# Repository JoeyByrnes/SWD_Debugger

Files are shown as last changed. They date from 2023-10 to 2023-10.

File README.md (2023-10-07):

# SWD_Debugger
Design files for an SWD debugger based on the <a href="https://github.com/electronut/ElectronutLabs-Bumpy">bumpy probe</a>. Compatible with Black Magic Probe and ST-Link V2 firmware. 

Hardware Changes from Bumpy 2.0 Project:
- Changed male USB-A plug to a female USB-C receptacle
- Changed pinout of the SWD/UART pins so that all SWD related pins are on top and all UART & power pins are on bottom
- Changed form factor and created an enclosure out of a cover PCB and 3d printed spacers.
- Changed resonator to an equivalent option in a different package
- Changed STM32 to a different package of the same product (for sourcing purposes at the time of designing)
<br>
<br>
<p align="center">
  
</p>

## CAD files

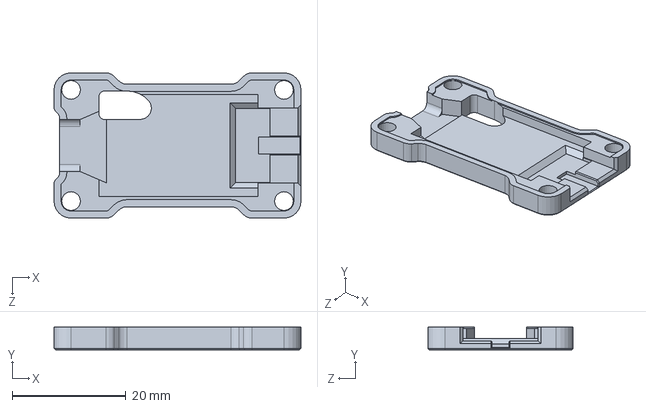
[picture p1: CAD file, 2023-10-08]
3D_Prints/Debugger_Print_Top.SLDPRT
43.5 x 4.00 x 25.6 mm

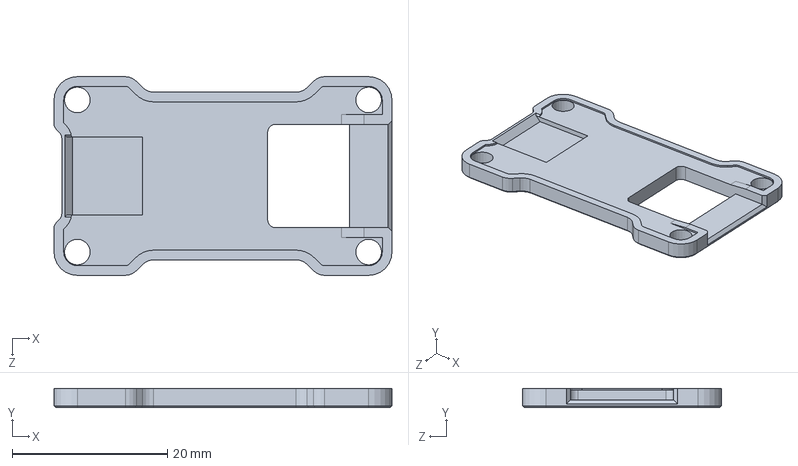
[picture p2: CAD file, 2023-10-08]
3D_Prints/Debugger_Print_Bottom.SLDPRT
43.5 x 2.50 x 25.6 mm

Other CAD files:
3D_Prints/Debugger_Print_Bottom.STL
3D_Prints/Debugger_Print_Top.STL

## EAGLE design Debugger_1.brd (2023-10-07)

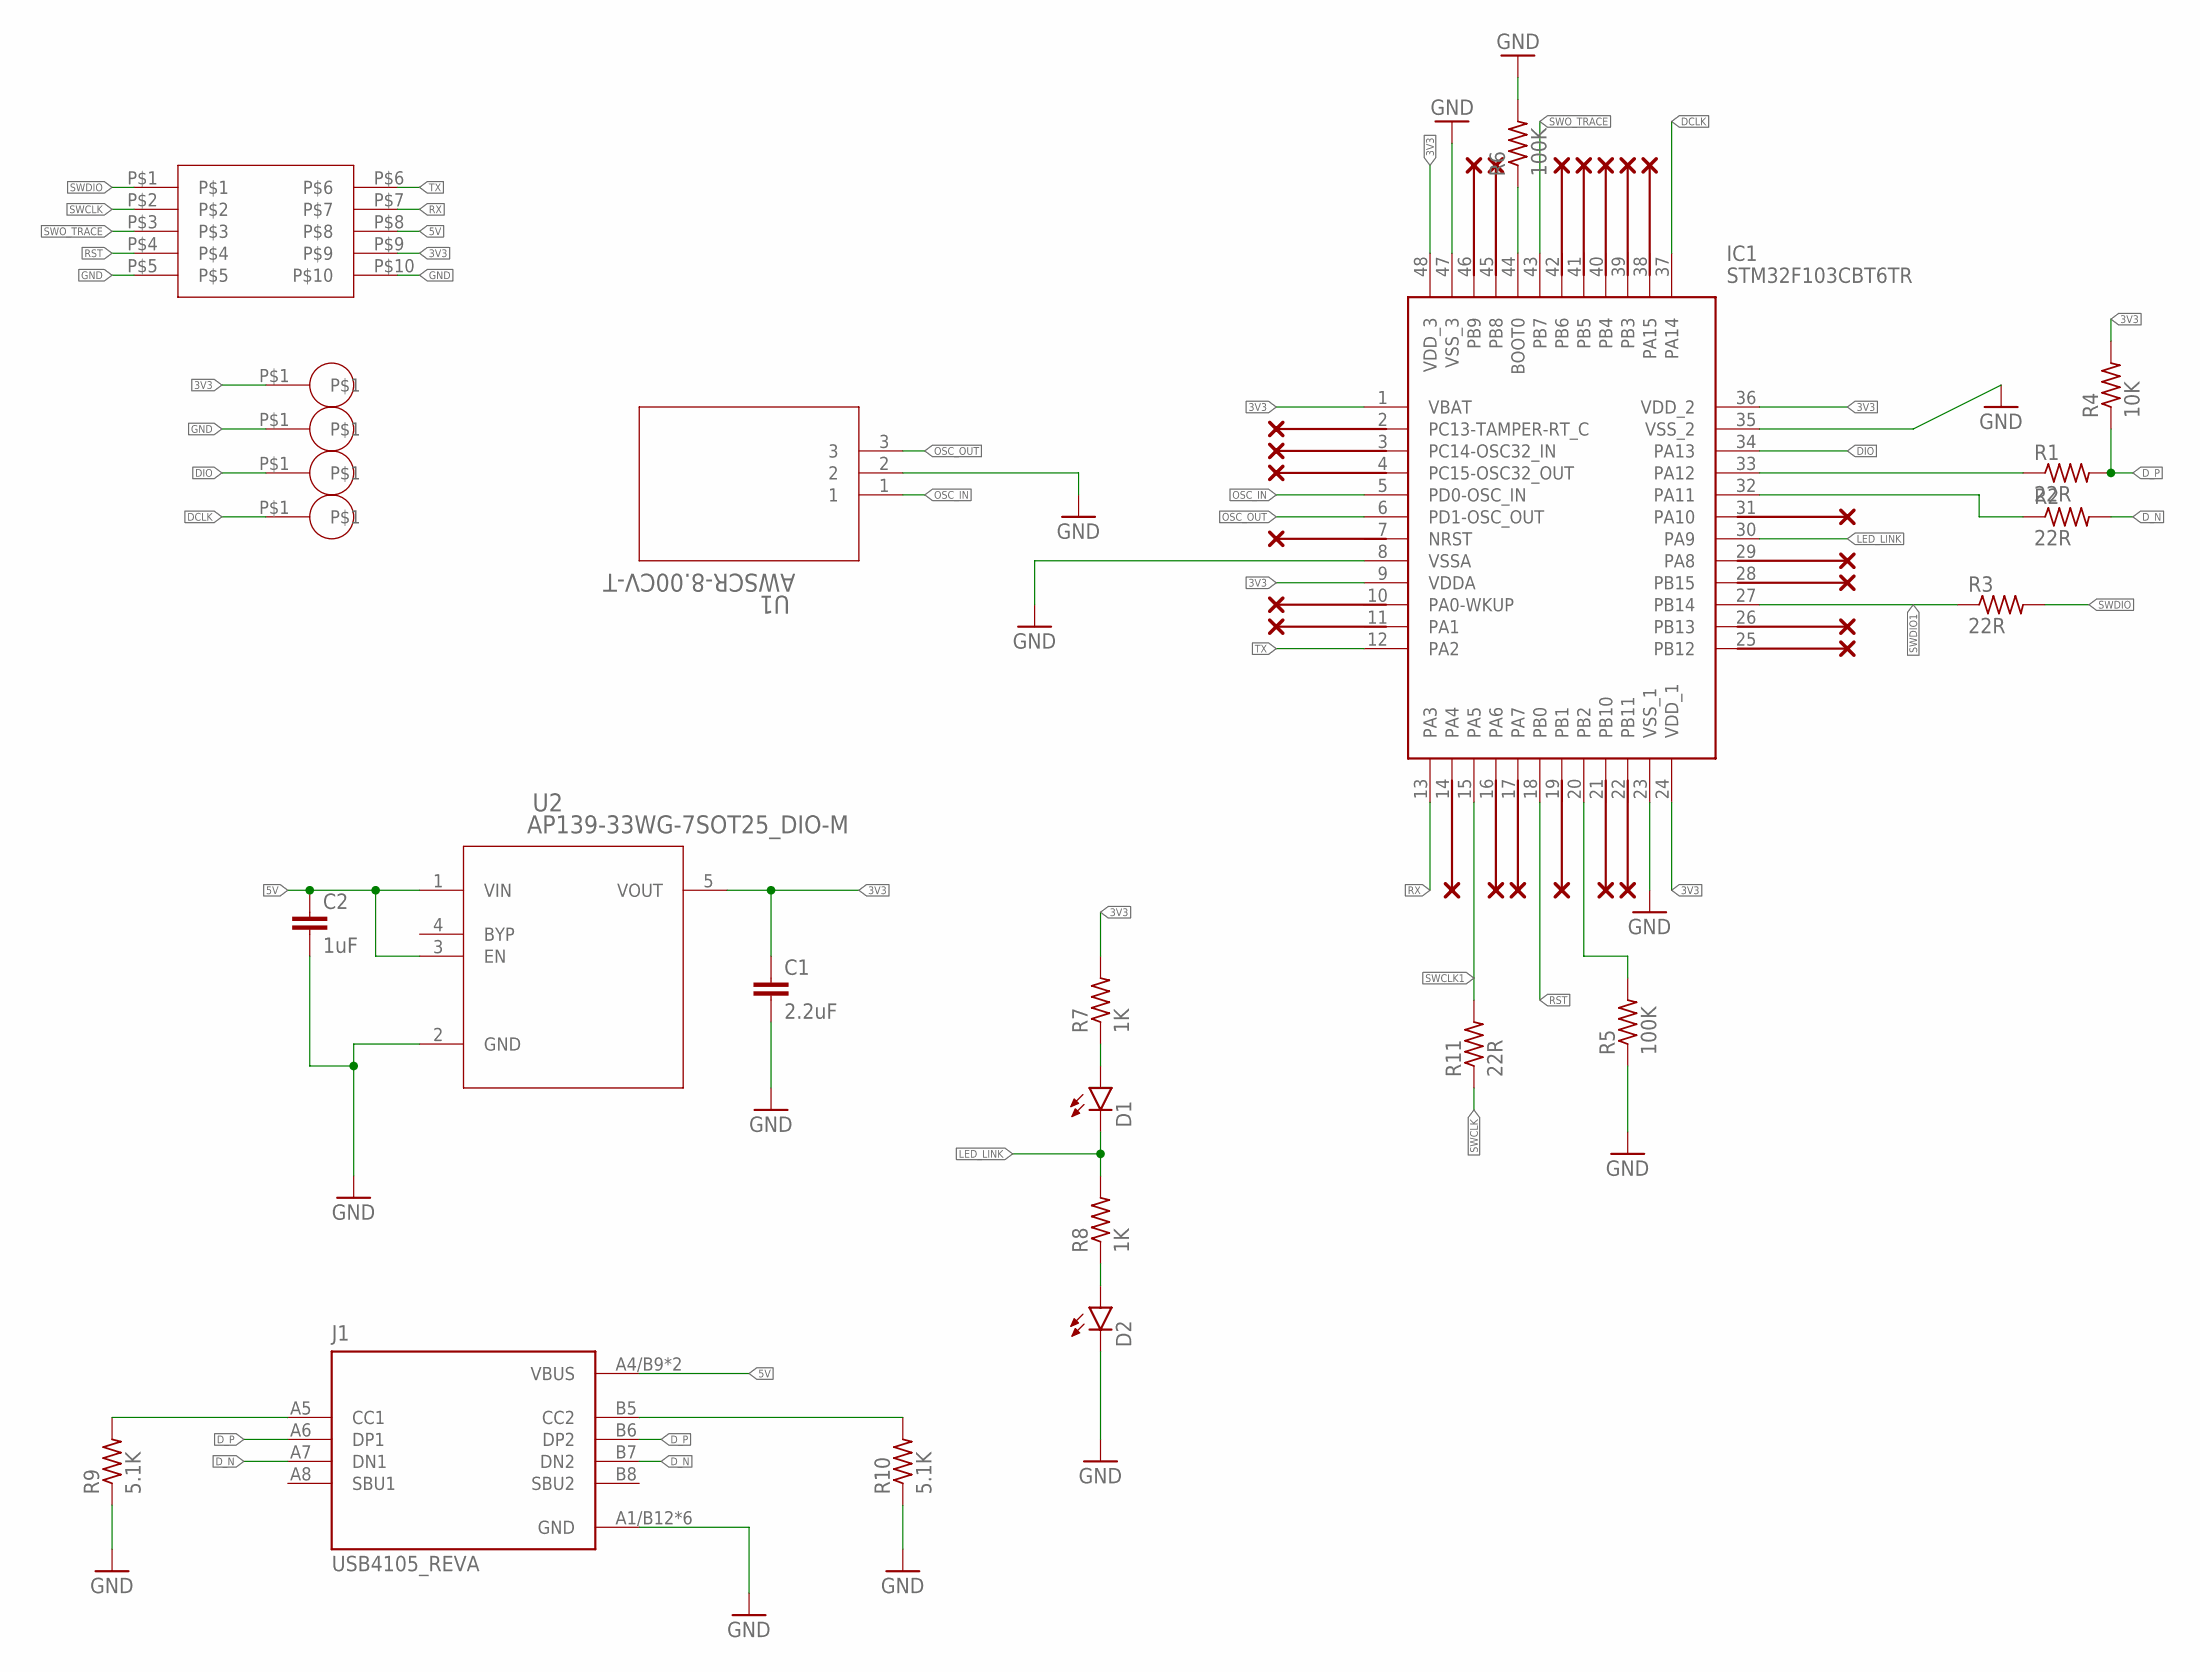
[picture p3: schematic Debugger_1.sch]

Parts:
C1: 2.2uF; C0603
C2: 1uF; C0603
D1, D2: LEDCHIPLED_0603; CHIPLED_0603
IC1: STM32F103CBT6TR; QFP50P900X900X160-48N
J1: USB4105_REVA; GCT_USB4105_REVA
R1, R2, R3, R11: 22R; R0603
R4: 10K; R0603
R5, R6: 100K; R0603
R7, R8: 1K; R0603
R9, R10: 5.1K; R0603
U1: AWSCR-8.00CV-T; AWSCR-8.00CV-T_ABR
U2: AP139-33WG-7SOT25_DIO-M; SOT25_DIO-M
U$25: SIDEWAYS_HEADER_10
U$26, U$27, U$28, U$29: SPRING_PAD_1

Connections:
3V3: C1.1, IC1.1 (VBAT), IC1.9 (VDDA), IC1.24 (VDD_1), IC1.36 (VDD_2), IC1.48 (VDD_3), R4.2, R7.2, U2.5 (VOUT), U$25.P$9, U$26.P$1
5V: C2.1, J1.A4/B9 (VBUS), J1.B4/A9 (VBUS), U2.1 (VIN), U2.3 (EN), U$25.P$8
DCLK: IC1.37 (PA14), U$29.P$1
DIO: IC1.34 (PA13), U$28.P$1
D_N: J1.A7 (DN1), J1.B7 (DN2), R2.2
D_P: J1.A6 (DP1), J1.B6 (DP2), R1.2, R4.1
GND: C1.2, C2.2, D2.C, IC1.8 (VSSA), IC1.23 (VSS_1), IC1.35 (VSS_2), IC1.47 (VSS_3), J1.A1/B12 (GND), J1.B1/A12 (GND), J1.G1 (GND), J1.G2 (GND), J1.G3 (GND), J1.G4 (GND), R5.1, R6.2, R9.1, R10.1, U1.2, U2.2 (GND), U$25.P$5, U$25.P$10, U$27.P$1
LED_LINK: D1.C, IC1.30 (PA9), R8.2
unnamed: IC1.20 (PB2), R5.2
unnamed: IC1.32 (PA11), R2.1
unnamed: IC1.33 (PA12), R1.1
unnamed: IC1.44 (BOOT0), R6.1
unnamed: D1.A, R7.1
unnamed: J1.A5 (CC1), R9.2
unnamed: D2.A, R8.1
unnamed: J1.B5 (CC2), R10.2
OSC_IN: IC1.5 (PD0-OSC_IN), U1.1
OSC_OUT: IC1.6 (PD1-OSC_OUT), U1.3
RST: IC1.18 (PB0), U$25.P$4
RX: IC1.13 (PA3), U$25.P$7
SWCLK: R11.1, U$25.P$2
SWCLK1: IC1.15 (PA5), R11.2
SWDIO: R3.2, U$25.P$1
SWDIO1: IC1.27 (PB14), R3.1
SWO_TRACE: IC1.43 (PB7), U$25.P$3
TX: IC1.12 (PA2), U$25.P$6

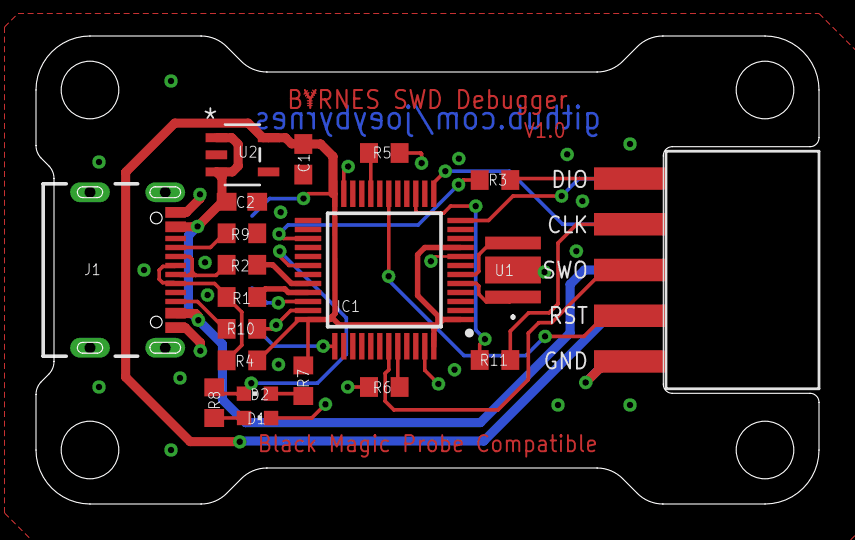
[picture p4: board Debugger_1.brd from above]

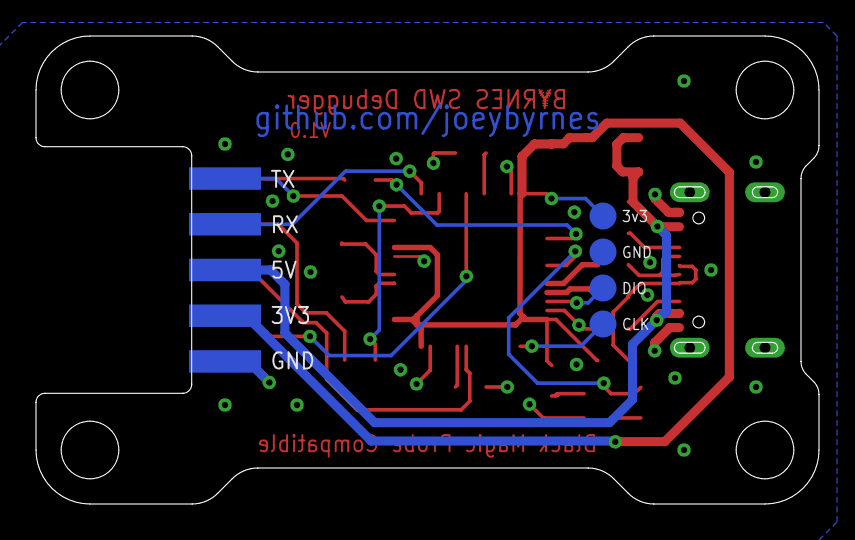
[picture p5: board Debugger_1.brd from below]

Board: 2 copper layers, 43.5 x 26.0 mm, 24 parts (4 on the bottom side), 26 nets.

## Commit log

2023-10-07 added source and gerber files
    [Debugger_1.brd, Debugger_1.sch, Debugger_Cover_1.brd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]
2023-10-08 Added enclosure 3d print files
    [Debugger_Print_Bottom.SLDPRT, Debugger_Print_Bottom.STL, Debugger_Print_Top.SLDPRT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]

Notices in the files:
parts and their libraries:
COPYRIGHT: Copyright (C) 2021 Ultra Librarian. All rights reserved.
